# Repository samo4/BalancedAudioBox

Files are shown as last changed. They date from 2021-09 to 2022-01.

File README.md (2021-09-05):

# BalancedAudioBox

USB connected balanced +4dBu DAC. Also USB powered. And allegedly 384kHz/32bit.



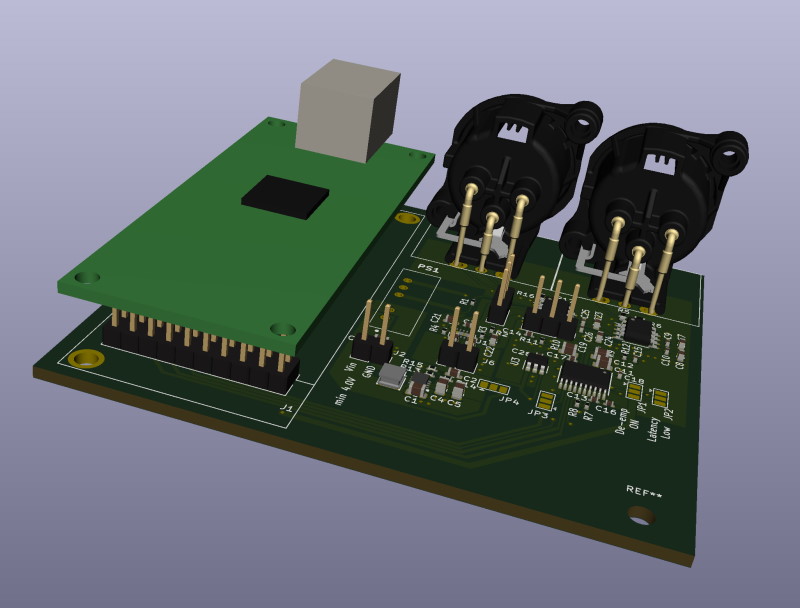
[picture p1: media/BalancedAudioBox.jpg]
Balanced Audio Box render


### Background

I have Genelec active speakers that only have balanced +4dBU input. I only use computer (orginally Intel NUC) as source and I wanted a DAC without any extra wires. There are many comercially availible DAC's, but the selection with balanced output is limited and I also wanted USB powered one without any extra features.

### Status

The first prototype is working great, documentation is under construction.

## How to make one

It's an electronics project, so you can use gerbers to make boards, buy components at your favourite distributor, buy [USB to I2S board](https://amanero.com/) or chinese clone, 3D print the enclosure and assemble everything.

STEP files are included, and here's [the link](https://a360.co/3yRnoUF) to Fusion.

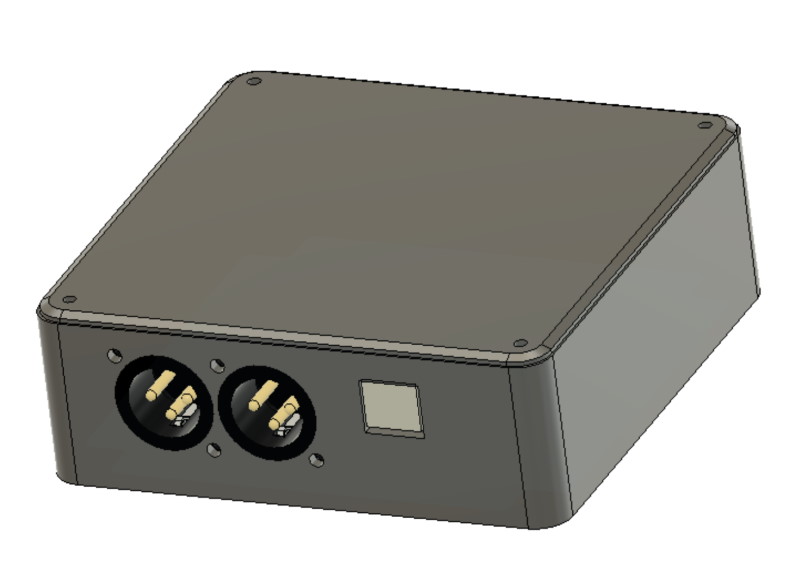
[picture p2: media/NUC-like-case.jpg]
NUC inspired case


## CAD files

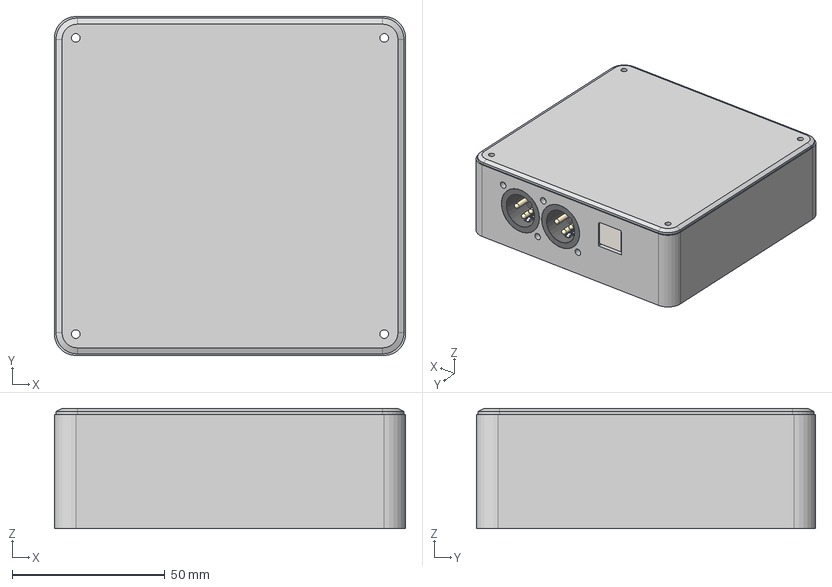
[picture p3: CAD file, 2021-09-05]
hardware/BalancedAudioBox.step
115.0 x 111.0 x 39.3 mm
PCB
Bottom Case
Cover

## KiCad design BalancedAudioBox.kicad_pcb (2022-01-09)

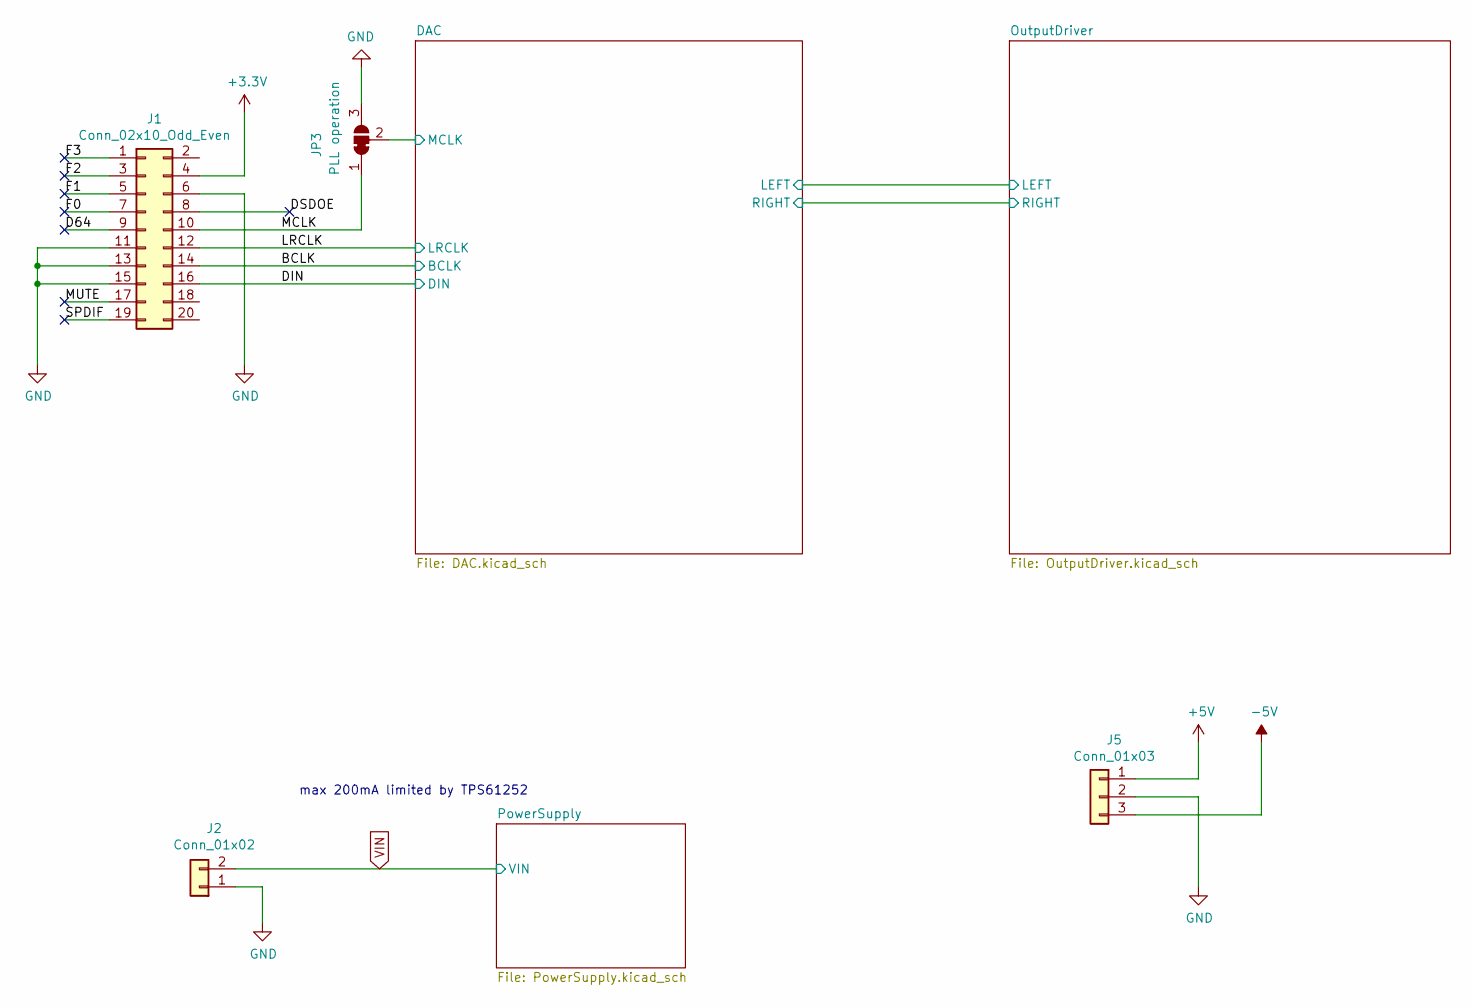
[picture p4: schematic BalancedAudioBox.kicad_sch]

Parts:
J1: Conn_02x10_Odd_Even; XMOS_USB_Board_2x10_P2.54mm
J2: Conn_01x02; PinHeader_1x02_P2.54mm_Vertical
J5: Conn_01x03; PinHeader_1x03_P2.54mm_Vertical
JP3: PLL operation; SolderJumper-3_P1.3mm_Bridged12_Pad1.0x1.5mm

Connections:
+3V3: J1.4; also elsewhere on the board
+5V: J5.1; also elsewhere on the board
-5V: J5.3; also elsewhere on the board
/BCLK: J1.14; also elsewhere on the board
/D64: J1.9
/DAC/MCLK: JP3.2 (C); also elsewhere on the board
/DIN: J1.16; also elsewhere on the board
/DSDOE: J1.8
/F0: J1.7
/F1: J1.5
/F2: J1.3
/F3: J1.1
/LRCLK: J1.12; also elsewhere on the board
/MCLK: J1.10, JP3.1 (A)
/MUTE: J1.17
/SPDIF: J1.19
GND: J1.6, J1.11, J1.13, J1.15, J2.1, J5.2, JP3.3 (B); also elsewhere on the board
VIN: J2.2; also elsewhere on the board

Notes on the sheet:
max 200mA limited by TPS61252

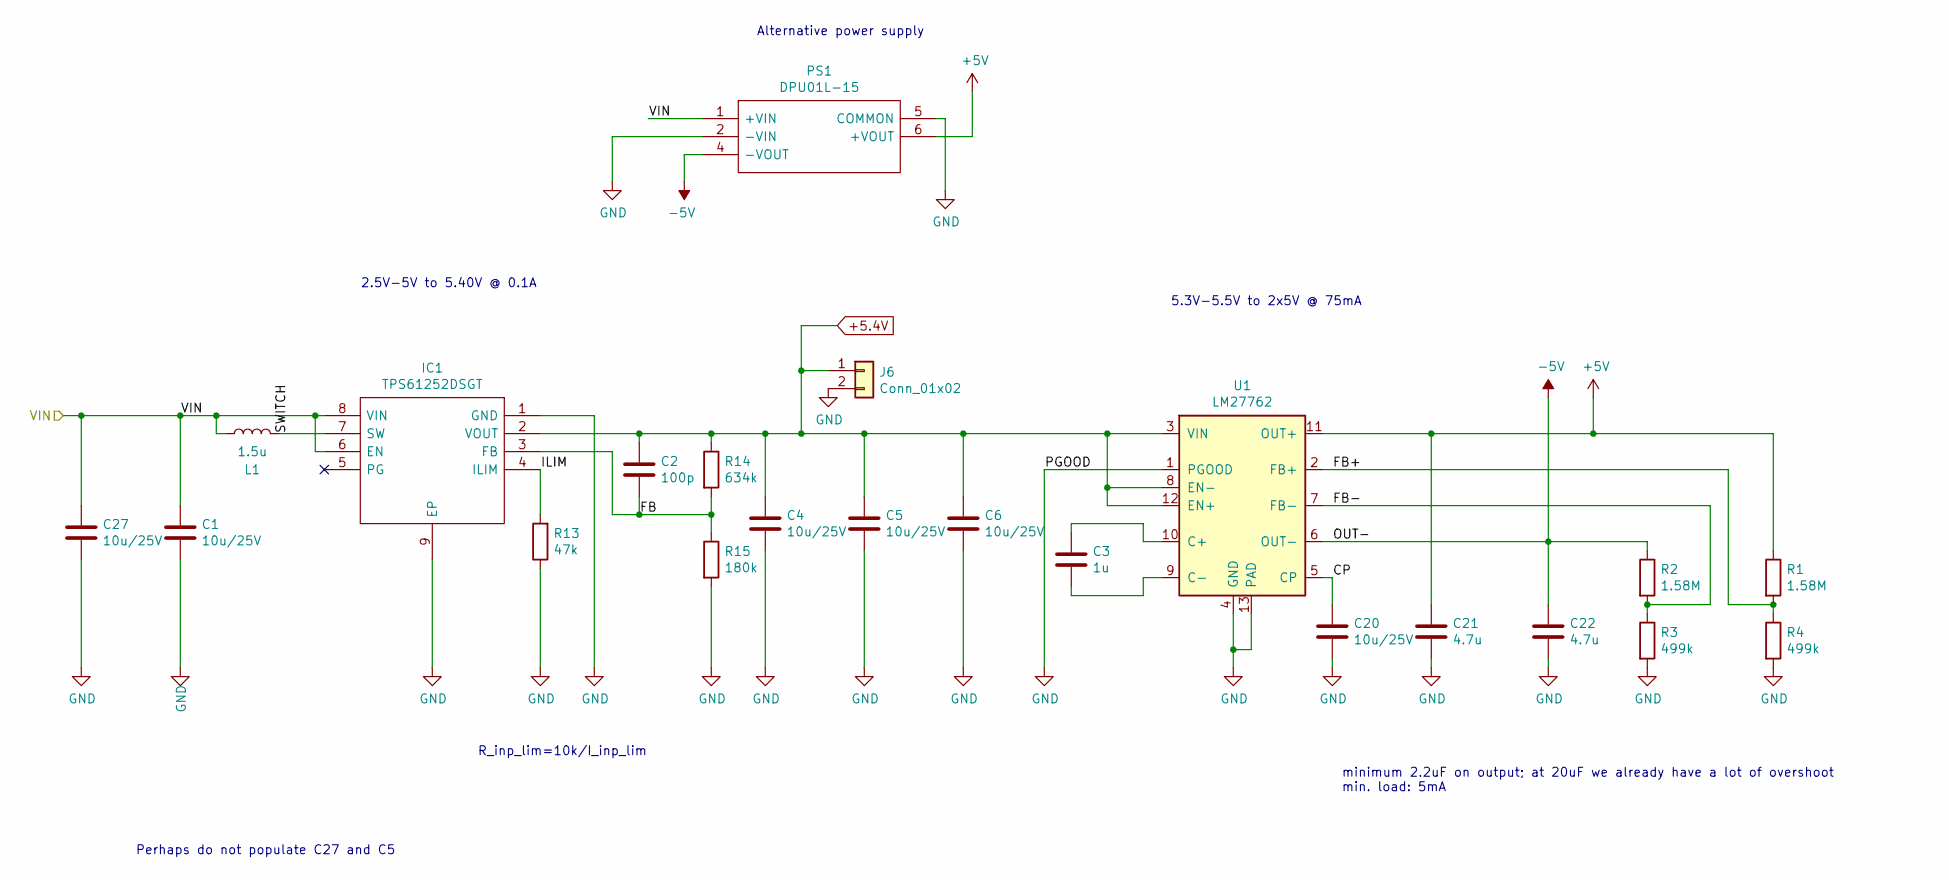
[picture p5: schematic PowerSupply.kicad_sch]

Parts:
C1, C4, C5, C6, C20, C27: 10u/25V; C_0805_2012Metric
C2: 100p; C_0603_1608Metric
C3: 1u; C_0402_1005Metric
C21, C22: 4.7u; C_0603_1608Metric
IC1: TPS61252DSGT; SON50P200X200X80-9N; Manufacturer_Part_Number TPS61252DSGT; Mouser Part Number 595-TPS61252DSGT
J6: Conn_01x02; PinHeader_1x02_P2.54mm_Vertical
L1: 1.5u; SRN30151R5Y
PS1: DPU01L-15; DPU01L15; Manufacturer_Part_Number DPU01L-15; Mouser Part Number 709-DPU01L-15
R1, R2: 1.58M; R_0402_1005Metric
R3, R4: 499k; R_0402_1005Metric
R13: 47k; R_0402_1005Metric
R14: 634k; R_0402_1005Metric
R15: 180k; R_0402_1005Metric
U1: LM27762; WSON-12-1EP_3x2mm_P0.5mm_EP1x2.65_ThermalVias

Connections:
+5.4V: C2.1, C4.1, C5.1, C6.1, IC1.2 (VOUT), J6.1, R14.1, U1.3 (VIN), U1.8 (EN-), U1.12 (EN+); also elsewhere on the board
+5V: C21.1, PS1.6 (+VOUT), R1.1, U1.11 (OUT+); also elsewhere on the board
-5V: C22.1, PS1.4 (-VOUT), R2.1, U1.6 (OUT-); also elsewhere on the board
/PowerSupply/CP: C20.1, U1.5 (CP)
/PowerSupply/FB: C2.2, IC1.3 (FB), R14.2, R15.1
/PowerSupply/FB+: R1.2, R4.1, U1.2 (FB+)
/PowerSupply/FB-: R2.2, R3.1, U1.7 (FB-)
/PowerSupply/ILIM: IC1.4 (ILIM), R13.2
/PowerSupply/SWITCH: IC1.7 (SW), L1.2
GND: C1.2, C4.2, C5.2, C6.2, C20.2, C21.2, C22.2, C27.2, IC1.1 (GND), IC1.9 (EP), J6.2, PS1.2 (-VIN), PS1.5 (COMMON), R3.2, R4.2, R13.1, R15.2, U1.1 (PGOOD), U1.4 (GND), U1.13 (PAD); also elsewhere on the board
unnamed: C3.1, U1.10 (C+)
unnamed: C3.2, U1.9 (C-)
VIN: C1.1, C27.1, IC1.6 (EN), IC1.8 (VIN), L1.1, PS1.1 (+VIN); also elsewhere on the board

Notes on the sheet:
5.3V-5.5V to 2x5V @ 75mA
R_inp_lim=10k/I_inp_lim
Perhaps do not populate C27 and C5
2.5V-5V to 5.40V @ 0.1A
Alternative power supply
minimum 2.2uF on output; at 20uF we already have a lot of overshoot min. load: 5mA

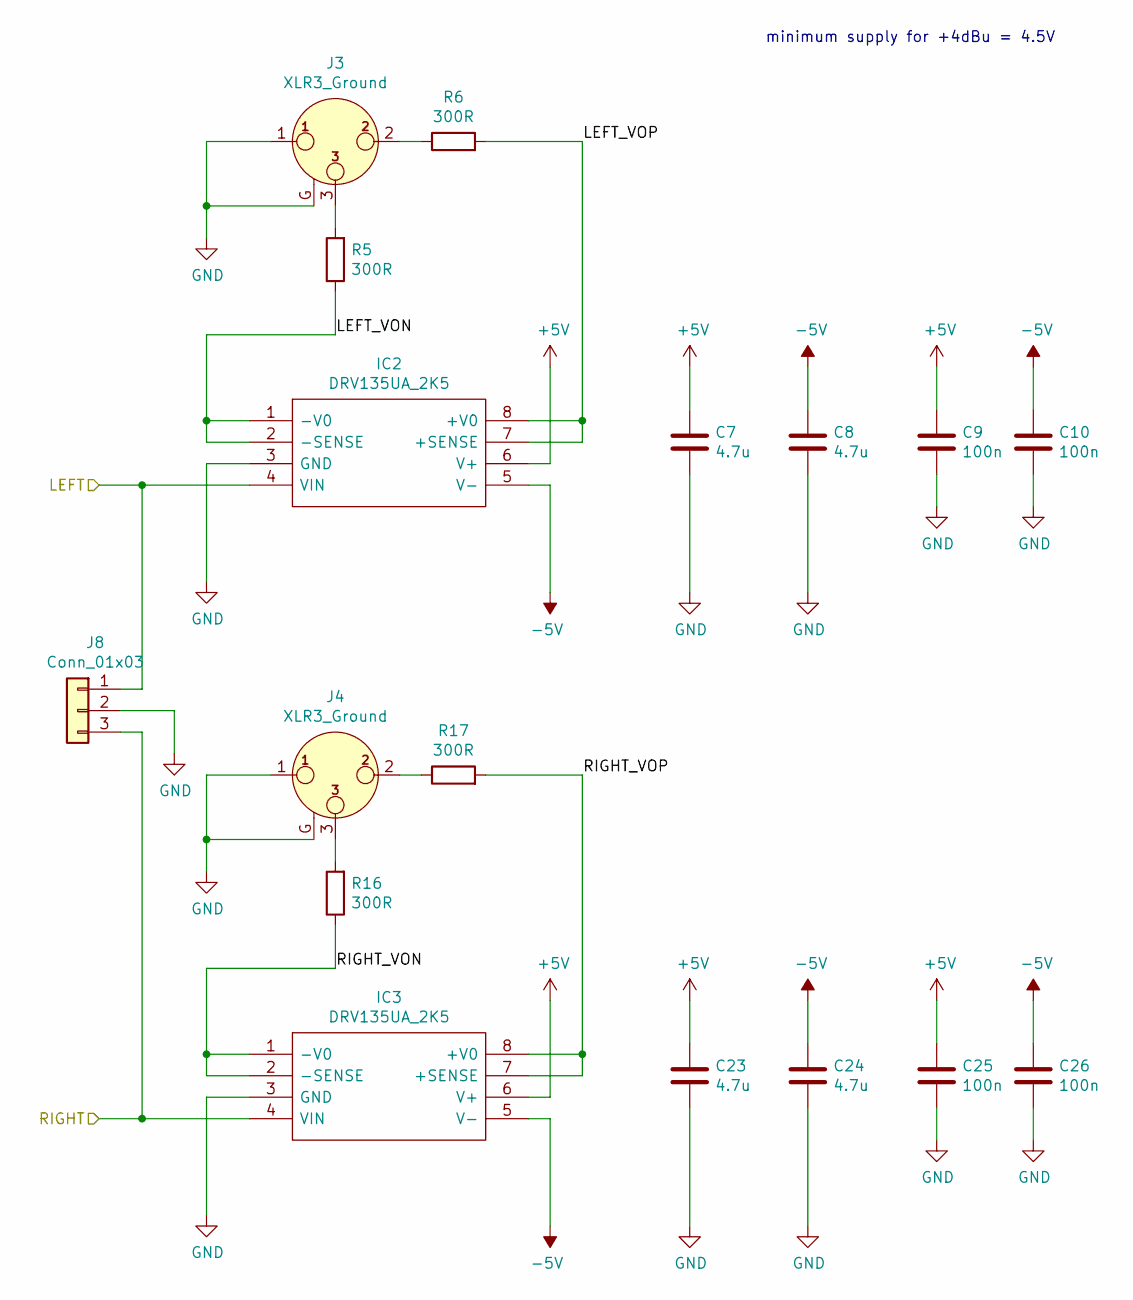
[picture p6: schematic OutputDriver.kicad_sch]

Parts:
C7, C8, C23, C24: 4.7u; C_0603_1608Metric
C9, C10, C25, C26: 100n; C_0402_1005Metric
IC2, IC3: DRV135UA_2K5; SOIC-8_3.9x4.9mm_P1.27mm; Manufacturer_Part_Number DRV135UA/2K5; Mouser Part Number 595-DRV135UA/2K5
J3, J4: XLR3_Ground; XLR-NC3MA
J8: Conn_01x03; PinHeader_1x03_P2.54mm_Vertical
R5, R6, R16, R17: 300R; R_0603_1608Metric

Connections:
+5V: C7.1, C9.1, C23.1, C25.1, IC2.6 (V+), IC3.6 (V+); also elsewhere on the board
-5V: C8.1, C10.1, C24.1, C26.1, IC2.5 (V-), IC3.5 (V-); also elsewhere on the board
/DAC/LEFT: IC2.4 (VIN), J8.1; also elsewhere on the board
/DAC/RIGHT: IC3.4 (VIN), J8.3; also elsewhere on the board
/OutputDriver/LEFT_VON: IC2.1 (-V0), IC2.2 (-SENSE), R5.1
/OutputDriver/LEFT_VOP: IC2.7 (+SENSE), IC2.8 (+V0), R6.2
/OutputDriver/RIGHT_VON: IC3.1 (-V0), IC3.2 (-SENSE), R16.1
/OutputDriver/RIGHT_VOP: IC3.7 (+SENSE), IC3.8 (+V0), R17.2
GND: C7.2, C8.2, C9.2, C10.2, C23.2, C24.2, C25.2, C26.2, IC2.3 (GND), IC3.3 (GND), J3.1, J3.G, J4.1, J4.G, J8.2; also elsewhere on the board
unnamed: J3.2, R6.1
unnamed: J3.3, R5.2
unnamed: J4.2, R17.1
unnamed: J4.3, R16.2

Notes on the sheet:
minimum supply for +4dBu = 4.5V

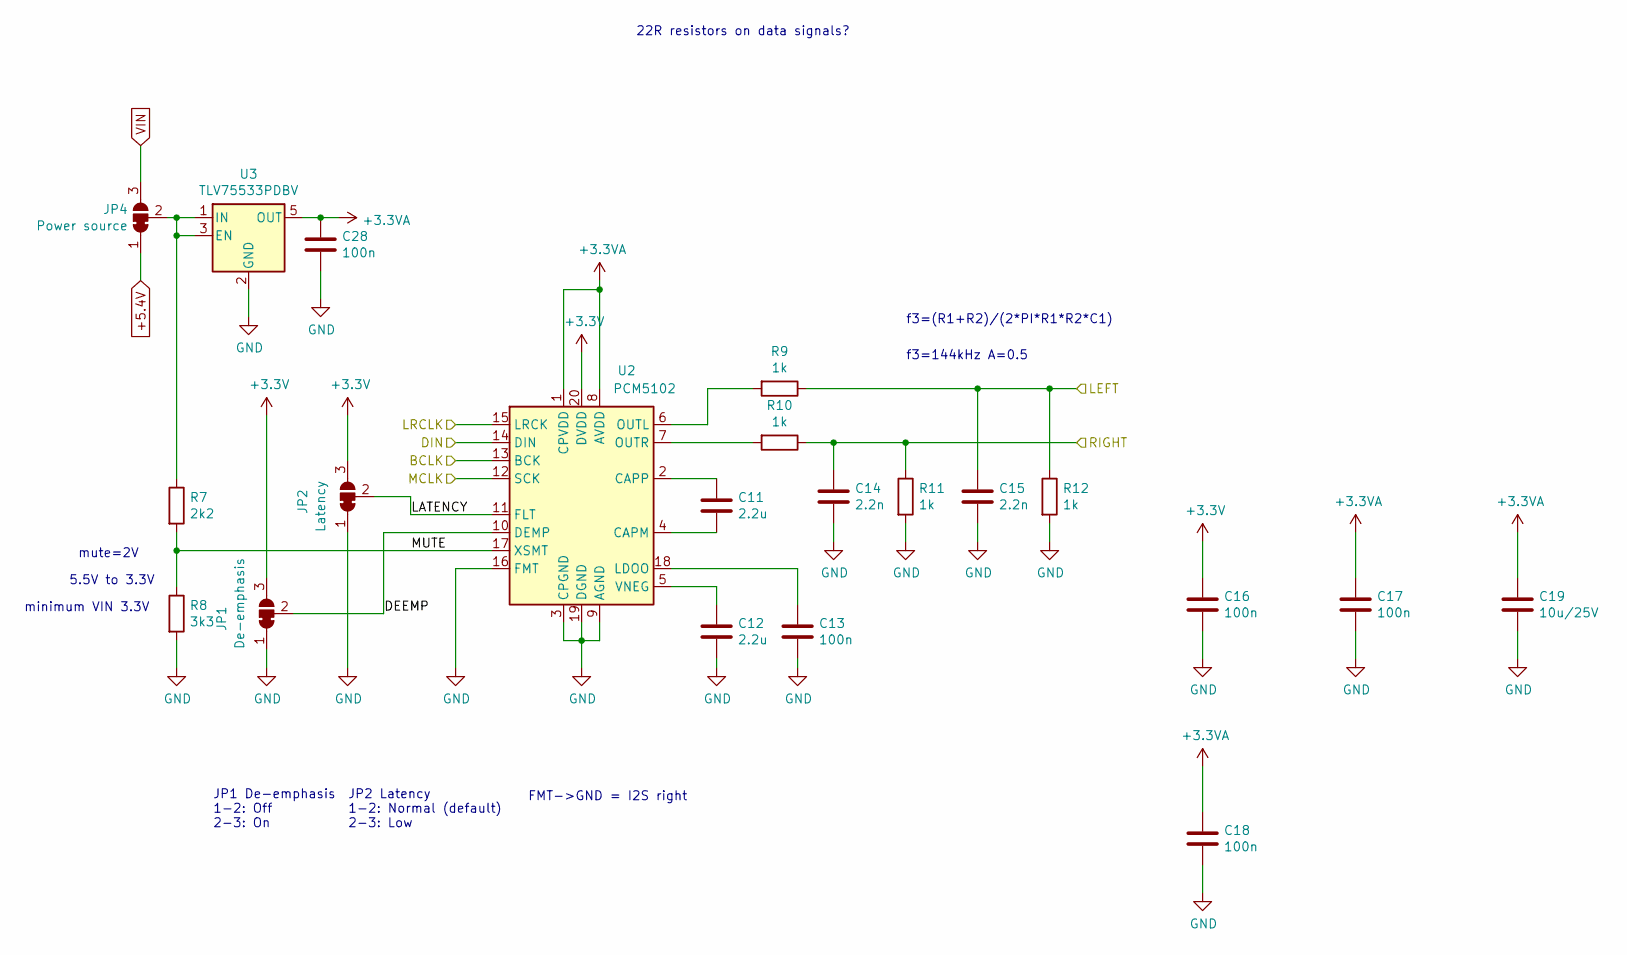
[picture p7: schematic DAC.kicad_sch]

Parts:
C11, C12: 2.2u; C_0805_2012Metric
C13, C16, C17, C18, C28: 100n; C_0402_1005Metric
C14, C15: 2.2n; C_0402_1005Metric
C19: 10u/25V; C_0805_2012Metric
JP1: De-emphasis; SolderJumper-3_P1.3mm_Bridged12_Pad1.0x1.5mm
JP2: Latency; SolderJumper-3_P1.3mm_Bridged12_Pad1.0x1.5mm
JP4: Power source; SolderJumper-3_P1.3mm_Bridged12_Pad1.0x1.5mm
R7: 2k2; R_0402_1005Metric
R8: 3k3; R_0402_1005Metric
R9, R10, R11, R12: 1k; R_0402_1005Metric
U2: PCM5102; TSSOP-20_4.4x6.5mm_P0.65mm
U3: TLV75533PDBV; SOT-23-5

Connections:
+3.3VA: C17.1, C18.1, C19.1, C28.1, U2.1 (CPVDD), U2.8 (AVDD), U3.5 (OUT)
+3V3: C16.1, JP1.3 (B), JP2.3 (B), U2.20 (DVDD); also elsewhere on the board
+5.4V: JP4.1 (A); also elsewhere on the board
/BCLK: U2.13 (BCK); also elsewhere on the board
/DAC/DEEMP: JP1.2 (C), U2.10 (DEMP)
/DAC/LATENCY: JP2.2 (C), U2.11 (FLT)
/DAC/LEFT: C15.1, R9.1, R12.1; also elsewhere on the board
/DAC/MCLK: U2.12 (SCK); also elsewhere on the board
/DAC/MUTE: R7.2, R8.1, U2.17 (XSMT)
/DAC/RIGHT: C14.1, R10.1, R11.1; also elsewhere on the board
/DIN: U2.14 (DIN); also elsewhere on the board
/LRCLK: U2.15 (LRCK); also elsewhere on the board
GND: C12.2, C13.2, C14.2, C15.2, C16.2, C17.2, C18.2, C19.2, C28.2, JP1.1 (A), JP2.1 (A), R8.2, R11.2, R12.2, U2.3 (CPGND), U2.9 (AGND), U2.16 (FMT), U2.19 (DGND), U3.2 (GND); also elsewhere on the board
unnamed: C11.1, U2.2 (CAPP)
unnamed: C11.2, U2.4 (CAPM)
unnamed: C12.1, U2.5 (VNEG)
unnamed: C13.1, U2.18 (LDOO)
unnamed: JP4.2 (C), R7.1, U3.1 (IN), U3.3 (EN)
unnamed: R9.2, U2.6 (OUTL)
unnamed: R10.2, U2.7 (OUTR)
VIN: JP4.3 (B); also elsewhere on the board

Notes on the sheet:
minimum VIN 3.3V
f3=144kHz A=0.5
mute=2V
JP1 De-emphasis 1-2: Off 2-3: On
5.5V to 3.3V
FMT->GND = I2S right
JP2 Latency 1-2: Normal (default) 2-3: Low
22R resistors on data signals?
f3=(R1+R2)/(2*PI*R1*R2*C1)

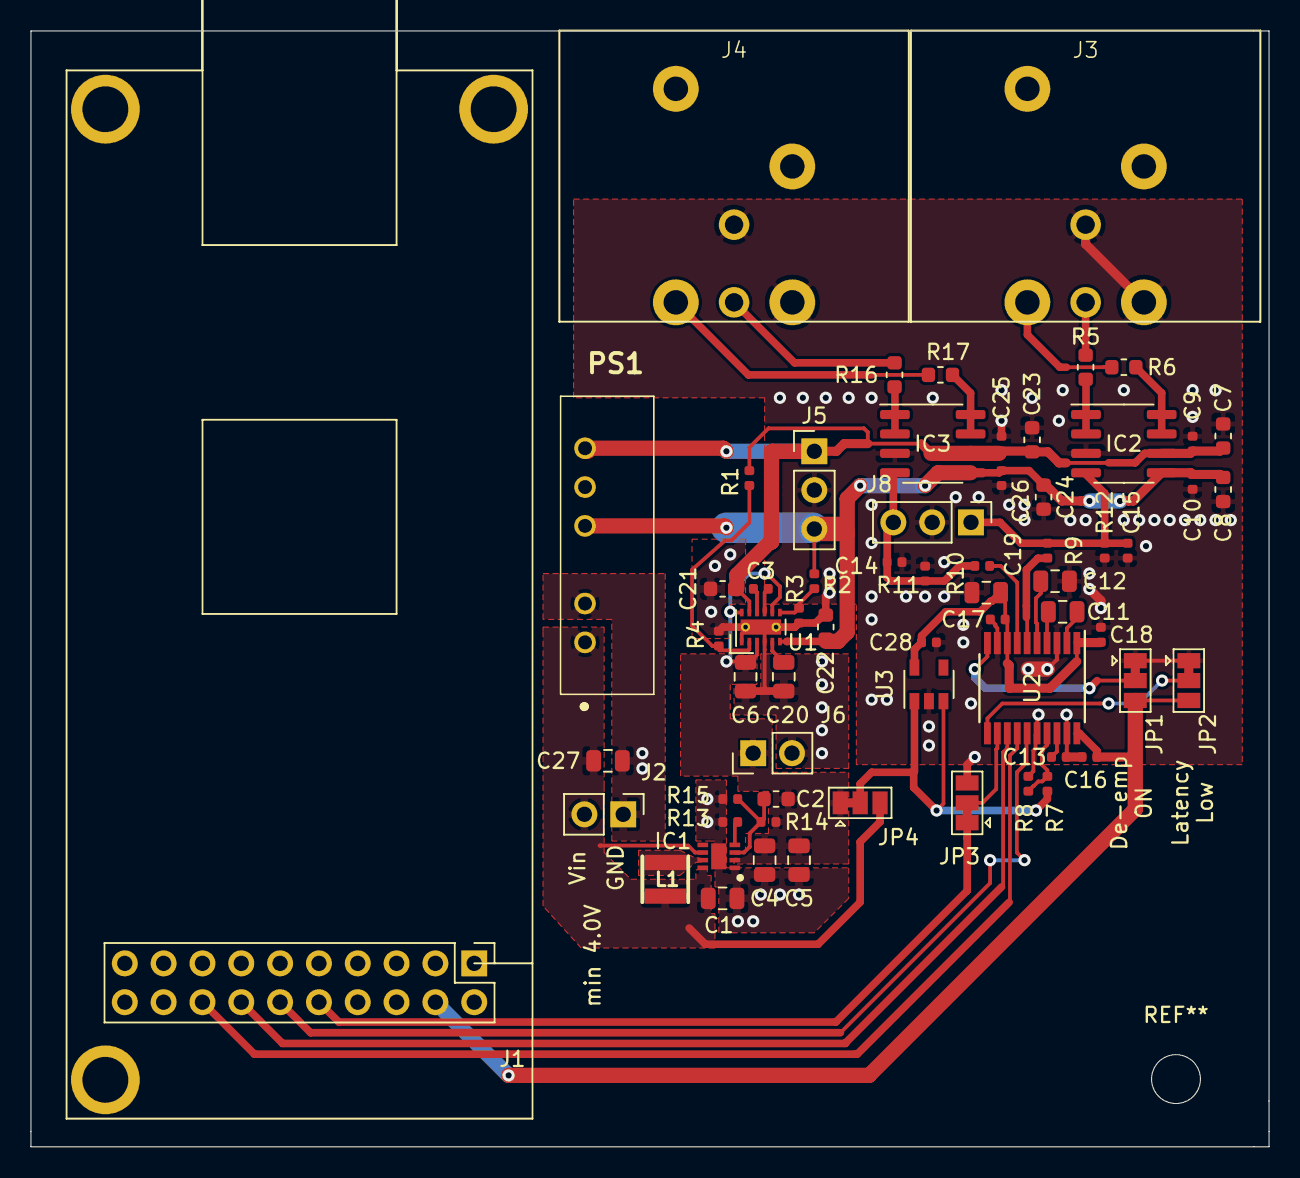
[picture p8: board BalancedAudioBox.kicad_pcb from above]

Board: 2 copper layers, 81.0 x 73.0 mm, 64 parts (0 on the bottom side), 40 nets.

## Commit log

2019-07-28 selecting actual components
    [BalancedAudioBox.sch, DAC.sch, OutputDriver.sch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]
2019-08-01 TPS61252 done
    [PowerSupply.sch]
2019-08-01 adding PCB libraries
    [BalancedAudioBox.kicad_pcb, BalancedAudioBox.sch, OutputDriver.sch]
2019-08-01 ps checked
    [BalancedAudioBox.sch, PowerSupply.sch]
2019-08-01 placement complete
    [BalancedAudioBox.kicad_pcb, BalancedAudioBox.sch, DAC.sch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]
2019-08-02 footprint and 3d improvements
    [BalancedAudioBox.kicad_pcb, PowerSupply.sch]
2019-08-02 layout and silk
    [BalancedAudioBox.kicad_pcb, BalancedAudioBox.sch, DAC.sch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]
2019-08-02 adding regulator
    [BalancedAudioBox.kicad_pcb, BalancedAudioBox.sch, DAC.sch]
2019-08-02 more layout
    [BalancedAudioBox.kicad_pcb, BalancedAudioBox.sch, DAC.sch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]
2019-11-24 larger conn
    [BalancedAudioBox.sch, DAC.sch, PowerSupply.sch]
2019-11-24 some routing
    [BalancedAudioBox.kicad_pcb]
2019-11-24 sch improv
    [DAC.sch, PowerSupply.sch]
2019-11-24 full route
    [BalancedAudioBox.kicad_pcb]
2019-12-22 smaller package, drc
    [BalancedAudioBox.kicad_pcb, BalancedAudioBox.sch, DAC.sch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]
2019-12-22 final tweaks
    [BalancedAudioBox.kicad_pcb]
2019-12-22 fix silk
    [BalancedAudioBox.kicad_pcb]
2019-12-30 solder paste at 90%; changed LDO
    [BalancedAudioBox.kicad_pcb, DAC.sch]
2021-09-05 adding gerbers (used for first prototype)
    [BalancedAudioBox-B_Cu.gbr, BalancedAudioBox-B_Mask.gbr, BalancedAudioBox-B_Paste.gbr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]
2021-09-05 adding case
2022-01-09 upgrade to 6
    [BalancedAudioBox.kicad_pcb, BalancedAudioBox.kicad_sch, BalancedAudioBox.sch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]

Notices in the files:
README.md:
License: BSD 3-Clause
